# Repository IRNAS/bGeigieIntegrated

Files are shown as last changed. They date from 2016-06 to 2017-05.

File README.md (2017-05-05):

# bGeigieIntegrated
#### Integrated version of Safecast bGeigie device

We created an integrated version of the bGeigie device, a mobile survey Geiger counter. Our PCB is based on orginal design by [Safecast](https://github.com/Safecast/bGeigieNanoKit). We removed various breakout boards and instead placed most of the components directly on the PCB. Our design uses [RedBear Duo](https://github.com/redbear/Duo) as a central processing unit, instead of Arduino Fio. The entire circuit can be powered through USB connector on RedBear, or from a 3.7V LiPo battery. The circuit also includes a battery charger. For control of the Geiger gas tube the iRover is being used, just like in the original design. A LED and a piezo buzzer signalyze the incoming pulses. FGPMMOPA6H GPS receiver from Adafruit retrieves the current position of the device and an accelerometer/magnetometer (LSM303C form ST Microelectronics) measures acceleration and orientation of it. Data are being logged on a micro SD card. A socket for the XBee module is also included, which enables connection to an external logger. A monochrome, 128x32 pixels wide OLED graphical display from [Adafruit](https://www.adafruit.com/product/938) displays a simple user interface. Accelerometer/magnetometer uses an I2C interface. SD card and OLED display communicate via SPI. XBee and GPS module are using an UART interface.

-

#### Changes in schematic:

* Power supply:
 * automatic switch between battery or USB powered mode
 * software power-down
* GPS module:
 * connection to battery
 * uFL connector for external antenna
* OLED display:
 * changed to I2C interface
 * added socket for alternative [display](https://www.amazon.com/Diymall%C2%AE-Yellow-Serial-Arduino-Display/dp/B00O2LLT30)
* magnetic buzzer with integrated oscillator
* high brigthess LEDs for COUNT and LOG indication
* added rotary encoder

---

#### License

All our projects are as usefully open-source as possible.

Hardware including documentation is licensed under [CERN OHL v.1.2. license](http://www.ohwr.org/licenses/cern-ohl/v1.2)

Firmware and software originating from the project is licensed under [GNU GENERAL PUBLIC LICENSE v3](http://www.gnu.org/licenses/gpl-3.0.en.html).

Open data generated by our projects is licensed under [CC0](https://creativecommons.org/publicdomain/zero/1.0/legalcode).

All our websites and additional documentation are licensed under [Creative Commons Attribution-ShareAlike 4 .0 Unported License] (https://creativecommons.org/licenses/by-sa/4.0/legalcode).

What this means is that you can use hardware, firmware, software and documentation without paying a royalty and knowing that you'll be able to use your version forever. You are also free to make changes but if you share these changes then you have to do so on the same conditions that you enjoy.

Koruza, GoodEnoughCNC and IRNAS are all names and marks of Institut IRNAS Rače. 
You may use these names and terms only to attribute the appropriate entity as required by the Open Licences referred to above. You may not use them in any other way and in particular you may not use them to imply endorsement or authorization of any hardware that you design, make or sell.

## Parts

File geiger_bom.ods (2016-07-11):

Designator | Package | Quantity | Description | Price (one piece) | Price (total) | Supplier link
U13 | SSD1306 blue, yellow 0.96" Inch OLED display module for Arduino, I2C | 1 | small I2C OLED | 9,790 € | 9,79 € | https://www.amazon.com/Diymall%C2%AE-Yellow-Serial-Arduino-Display/dp/B00O2LLT30 (https://www.amazon.com/Diymall®-Yellow-Serial-Arduino-Display/dp/B00O2LLT30)
U4 | Adafruit 1.3 inch 128x64 monochrome OLED display | 1 | OLED | 22,190 € | 22,19 € | https://www.adafruit.com/product/938
C1,C3,C4,C6,C7,C8,C9,C10,C12,C15,C17 | C0603 | 11 | 100nF | 0,007 € | 0,08 € | http://si.farnell.com/walsin/0603b104k250ct/capacitor-mlcc-x7r-0-1uf-25v-0603/dp/2496833RL
C16,C18 | C0603 | 2 | 10nF | 0,005 € | 0,01 € | http://si.farnell.com/walsin/0603b103k500ct/capacitor-mlcc-x7r-0-01uf-50v/dp/2496828
C20 | C0603 | 1 | 1uF | 0,009 € | 0,01 € | http://si.farnell.com/murata/grm188r61c105ka12d/cap-mlcc-x5r-1uf-16v-0603/dp/2362099
C2,C5,C11,C19 | tantalum capacitor size B | 4 | 10uF, 10V | 0,333 € | 1,33 € | http://si.farnell.com/kemet/t491b106k010at/cap-tant-10uf-10v-case-b/dp/2283564
C13,C14 | tantalum capacitor size B | 2 | 1uF, 10V | 0,444 € | 0,89 € | http://si.farnell.com/kemet/t491b105k025at/cap-tant-1uf-25v-case-b/dp/2321211
D1 | LED0603 | 1 | GREEN | 0,342 € | 0,34 € | http://si.farnell.com/vishay/tlmp1100-gs08/led-0603-green/dp/1328306
D2 | KPD-3224SURCK | 1 | RED | 0,132 € | 0,13 € | http://si.farnell.com/kingbright/kpd-3224surck/led-smd-dome-lens-red/dp/2146458
D3 | MCL053SGC | 1 | GREEN | 0,239 € | 0,24 € | http://si.farnell.com/multicomp/mcl053sgc/led-5mm-16-super-green/...
D4 | SOD-323 | 1 | 1N4148 | 0,057 € | 0,06 € | http://si.farnell.com/vishay-semiconductor/1n4148ws-e3-08/switching-diode-100v-150ma-sod/dp/2164233
D5 | LED0603 | 1 | RED | 0,285 € | 0,29 € | http://si.farnell.com/vishay/tlms1000-gs08/led-0603-red-4mcd-628nm/dp/1328308
D6 | SOD-323 | 1 | BAT20J | 0,291 € | 0,29 € | http://si.farnell.com/stmicroelectronics/bat20jfilm/diode-schottky-2a-23v/dp/1467541
P4 | B3B-PH-SM4-TB | 1 | IRover connector (receptacle) | 0,382 € | 0,38 € | http://si.farnell.com/jst-japan-solderless-terminals/b3b-ph-sm4-tb-lf-sn/connector-header-smt-2mm-3way/...
P7 | B2B-PH-SM4-TB | 1 | battery connector (receptacle) | 0,318 € | 0,32 € | http://si.farnell.com/jst-japan-solderless-terminals/b2b-ph-sm4-tb-lf-sn/connector-header-smt-2mm-2way/...
Q1,Q4 | SOT-23-3 | 2 | ZXMP6A13F | 0,447 € | 0,89 € | http://si.farnell.com/diodes-inc/zxmp6a13fta/mosfet-p-ch-60v-0-9a-sot23-3/dp/1843770
Q2,Q3,Q6,Q7 | SOT-23-3 | 4 | RSR010N10FHATL | 0,720 € | 2,88 € | http://si.farnell.com/rohm/rsr010n10fhatl/mosfet-n-ch-100v-1a-tsmt-3/dp/2527973
Q5 | SOT-23-3 | 1 | BC847C | 0,380 € | 0,38 € | http://si.farnell.com/nxp/bc847c-215/transistor-npn-45v-sot-23/dp/1081235
R1,R10,R13,R17,R18 | R0603 | 5 | 1K | 0,004 € | 0,02 € | http://si.farnell.com/multicomp/mcwr06x1001ftl/res-thick-film-1k-1-0-1w-0603/dp/2447272
R2,R9 | R0603 | 2 | 9.1K | 0,001 € | 0,00 € | http://si.farnell.com/multicomp/mc0063w060319k1/res-thick-film-9k1-1-0-063w-0603/dp/9331611
R3 | R0603 | 1 | 100K | 0,001 € | 0,00 € | http://si.farnell.com/multicomp/mc0063w06031100k/res-thick-film-100k-1-0-063w-0603/dp/9330402RL
R4,R5,R6,R7,R19,R27,R28,R29,R30,R31,R32,R33 | R0603 | 12 | 10K | 0,001 € | 0,01 € | http://si.farnell.com/multicomp/mc0063w0603110k/res-thick-film-10k-1-0-063w-0603/dp/9330399RL
R8,R12,R15,R16,R21 | R0603 | 5 | 470K | 0,001 € | 0,01 € | http://si.farnell.com/multicomp/mc0063w06031470k/res-thick-film-470k-1-0-063w-0603/dp/9331263RL
R11 | R0603 | 1 | 51R | 0,002 € | 0,00 € | http://si.farnell.com/multicomp/mc0063w0603151r/res-thick-film-51r-1-0-063w-0603/dp/9331336
R14 | R0603 | 1 | 51K | 0,001 € | 0,00 € | http://si.farnell.com/multicomp/mc0063w0603151k/res-thick-film-51k-1-0-063w-0603/dp/9331310RL
R20 | R0603 | 1 | 68R | 0,002 € | 0,00 € | http://si.farnell.com/multicomp/mc0063w0603168r/res-thick-film-68r-1-0-063w-0603/dp/9331484
R24,R25,R26 | R0603 | 2 | 0R | 0,003 € | 0,01 € | http://si.farnell.com/multicomp/mcwr06x000-ptl/res-thick-film-0-ohm-jumper-0/dp/2447743RL
SW2 | A6S-3102-H | 1 | switch DIP-3 | 1,214 € | 1,21 € | http://si.farnell.com/omron-electronic-components/a6s3102h/switch-dip-3-way-sealed/...
U1 | Adafruit Ultimate GPS Module - MTK3339 chipset | 1 | FGPMMOPA6H | 27,120 € | 27,12 € | https://www.adafruit.com/product/790
U2 | SOT-23-5 | 1 | MAX1555 | 2,070 € | 2,07 € | http://si.farnell.com/maxim-integrated-products/max1555ezk-t/battery-charger-li-ion-280ma-sot/dp/2516725
U3 | Xbee socket | 1 | XBee | 19,940 € | 19,94 € | http://si.farnell.com/digi-international/xb24-awi-001/rf-module-txrx-xbee-wire-ant/dp/1337912
U5 | MOLEX 47309-2651 | 1 | micro SD card slot | 1,540 € | 1,54 € | http://si.farnell.com/molex/47309-2651/connector-micro-sd-header-smt/dp/1568092
U6 | SOT-223-3 | 1 | MCP1826S, 3.3V | 0,661 € | 0,66 € | http://si.farnell.com/microchip/mcp1826s-3302e-db/ic-ldo-3-3v-1a-sot-223-3/...
U7 | RedBear Duo socket | 1 | RedBear Duo | 22,570 € | 22,57 € | https://store.redbear.cc/product/wifi-ble/redbear-duo.html
U9 | SOT-23-6 | 1 | LM3880 | 0,644 € | 0,64 € | http://si.farnell.com/texas-instruments/lm38801ae-nopb/power-sequencer-25ua-5-5v-sot/dp/2492198
U10 | SOT-23-5 | 1 | MIC5205, 3.3V | 0,382 € | 0,38 € | http://si.farnell.com/microchip/mic5205-3-3ym5-tr/ic-ldo-150ma-3-3v-ln-sot23-5/dp/2510222
U11 | LD-BZEG-1205 | 1 | magnetic buzzer with internal oscillator | 0,537 € | 0,54 € | http://www.tme.eu/gb/details/ld-bzeg-1205/electromagnetic-sounders-with-generator/loudity/
P1 | U.FL-R-SMT | 1 | uFL connector | 0,578 € | 0,58 € | http://si.farnell.com/hirose-hrs/u-fl-r-smt-1-10/rf-coaxial-u-fl-straight-jack/dp/1688077
SW1 | OS102011MA1QN1 | 1 | slide switch | 0,309 € | 0,31 € | http://si.farnell.com/c-k-components/os102011ma1qn1/switch-spdt-0-1a-12v-pcb-r-a/...
L1 | R0603 | 1 | ferrite bead | 0,036 € | 0,04 € | http://si.farnell.com/murata/blm18bb100sn1d/ferrite-bead-10-ohm-700ma-0603/dp/1515687
P2 | SeedStudio DIP Grove 4P-2.0 | 1 | I2C connector | 1,360 € | 1,36 € | https://www.seeedstudio.com/item_detail.html?p_id=789
U12 | Bourns EC12R-4217F-S0024 | 1 | rotary encoder with switch | 1,150 € | 1,15 € | http://eu.mouser.com/ProductDetail/Bourns/PEC12R-4217F-S0024/...
U14 | TSOT-23-6 | 1 | LTC4412 | 4,650 € | 4,65 € | http://si.farnell.com/linear-technology/ltc4412hs6-trmpbf/...
U15 | SOT-363-6 (SC-70) | 1 | Si1967DH | 0,300 € | 0,30 € | http://si.farnell.com/vishay/si1967dh-t1-ge3/mosfet-dual-p-channel-20v-1-3a/dp/2459406
U8 | LGA-12 | 1 | LSM303C | 2,620 € | 2,62 € | http://eu.mouser.com/ProductDetail/STMicroelectronics/LSM303CTR/?qs=sGAEpiMZZMvnsdhmqAkjhpKxrN6XHrqG
XX | JST PHR-3 | 1 | IRover connector (plug) | 0,090 € | 0,09 € | http://www.digikey.com/product-search/en?keywords=jst%20phr-3
 |  |  |  | Total: | 128,32 €

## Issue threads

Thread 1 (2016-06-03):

ReadBear resets when switching from battery to USB power supply

MatejGomboc, 2016-06-03:
ReadBear resets when switching from battery to USB power supply. No glicth on 3v3 line has been detected.

thinrope, 2016-11-15:
This seems to be by (mis-)design?
https://github.com/redbear/Duo/blob/4939729db3e4c0e1d01a7ab4786c5cb1f7083013/docs/duo_introduction.md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

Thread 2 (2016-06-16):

LSM303C wrong footprint

MatejGomboc, 2016-06-16:
The footprint of LSM303C is wrong.

MatejGomboc, 2016-06-20:
Corrected in version: 93a449f8909264a0c31f38d7b277a518afbb46ec.

Closed 2016-06-20.

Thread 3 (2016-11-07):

Accelerometer/Magnetometer Library Incompatible

MatejGomboc, 2016-11-07:
Library for accelerometer/magnetometer is incompatible with LSM303C.

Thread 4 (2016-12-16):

Some suggestions.

robouden, 2016-12-16:
- power switch bigger and stronger
- more options for displays (maybe jumpers)
- test for SPI display running on Redbear Duo wold be usefull

SloMusti, 2017-01-07:
Please list displays you believe would be useful and support can be added.

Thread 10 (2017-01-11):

Battery connector

SloMusti, 2017-01-11:
User a better battery connector, such that it does not break that simply.

SloMusti, 2017-01-12:
Also move connector about 5mm towards the inside of the board, so it is not on the edge.

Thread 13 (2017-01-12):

Buzzer dual drive

SloMusti, 2017-01-12:
Make the buzzer such that it receives the signal input at the same time from geiger tube and processor.

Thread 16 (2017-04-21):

Evaluate current consumption of small and large OLED display.

fakufaku, 2017-04-21:
@robouden used a large 2.4" display
vs
The standard 1.3" display used before

If the large display is used, it should be moved to the center of the pcb to appear in the large clear area of the Pelican case.

robouden, 2017-07-15:
Large OLED based unit runs 12 hours on a full charged 3000mA LiPo

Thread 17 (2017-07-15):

Charging Issues

robouden, 2017-07-15:
When the unit is charging it switch on and off. If let on long time the LiPo get overcharged, gets very hot  and start smelling.

robouden, 2017-07-15:
Would be nice if we could detect the unit is charging and disable the soft startup.

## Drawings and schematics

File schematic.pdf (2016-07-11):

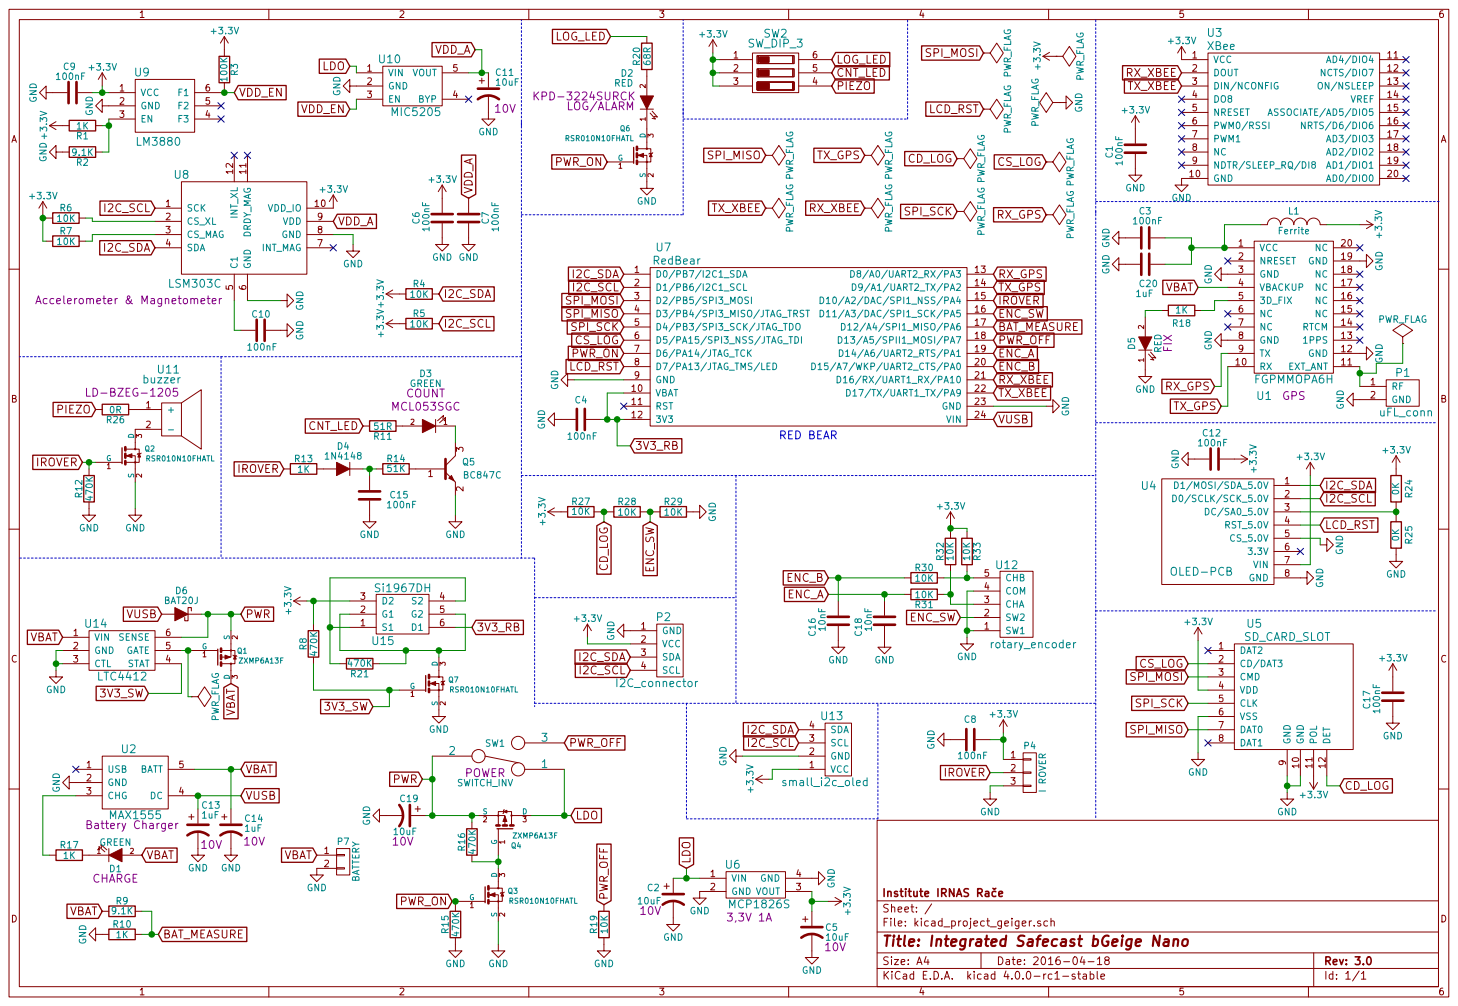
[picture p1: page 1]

9 GND 10 POL 11 DET 12 U5 SD_CARD_SLOT VBAT

Institute IRNAS Rae
File: kicad_project_geiger.sch Sheet: /
Id: 1/1 Title: Integrated Safecast bGeige Nano

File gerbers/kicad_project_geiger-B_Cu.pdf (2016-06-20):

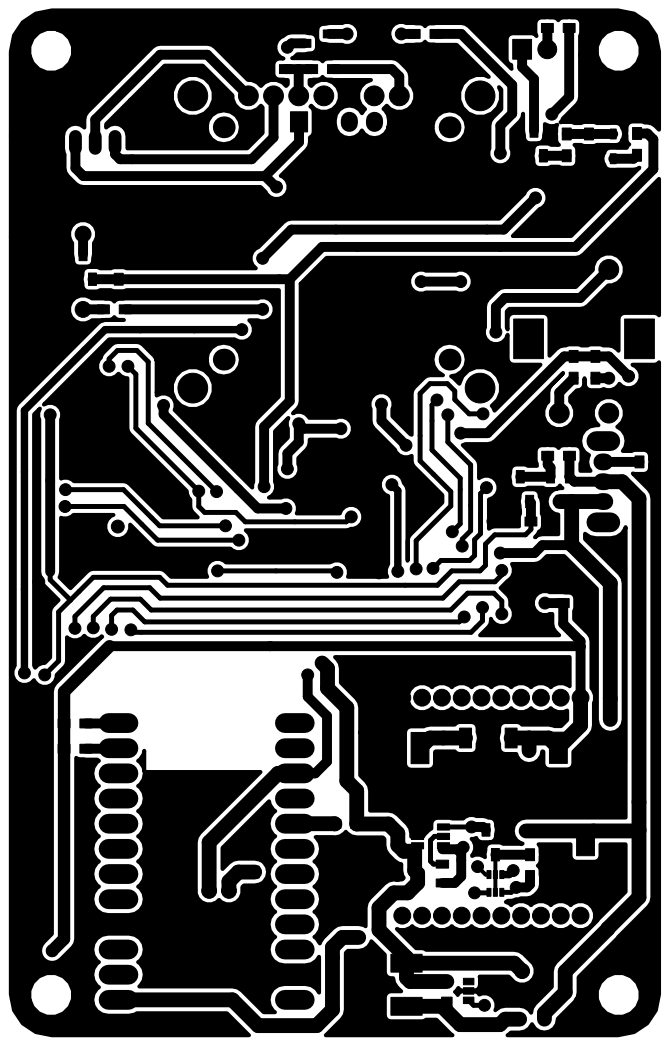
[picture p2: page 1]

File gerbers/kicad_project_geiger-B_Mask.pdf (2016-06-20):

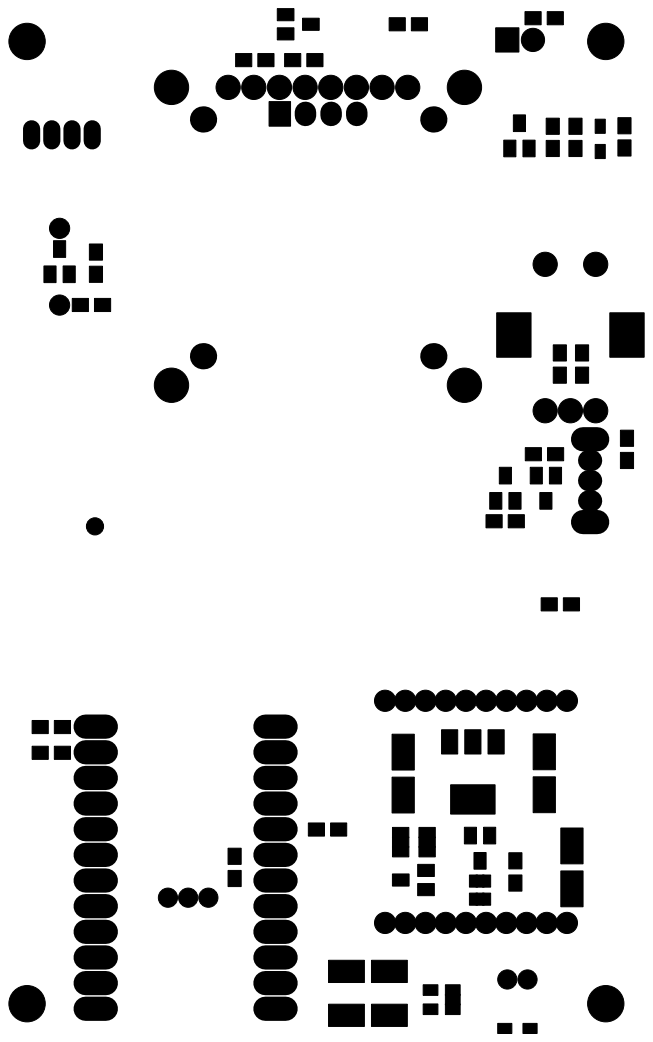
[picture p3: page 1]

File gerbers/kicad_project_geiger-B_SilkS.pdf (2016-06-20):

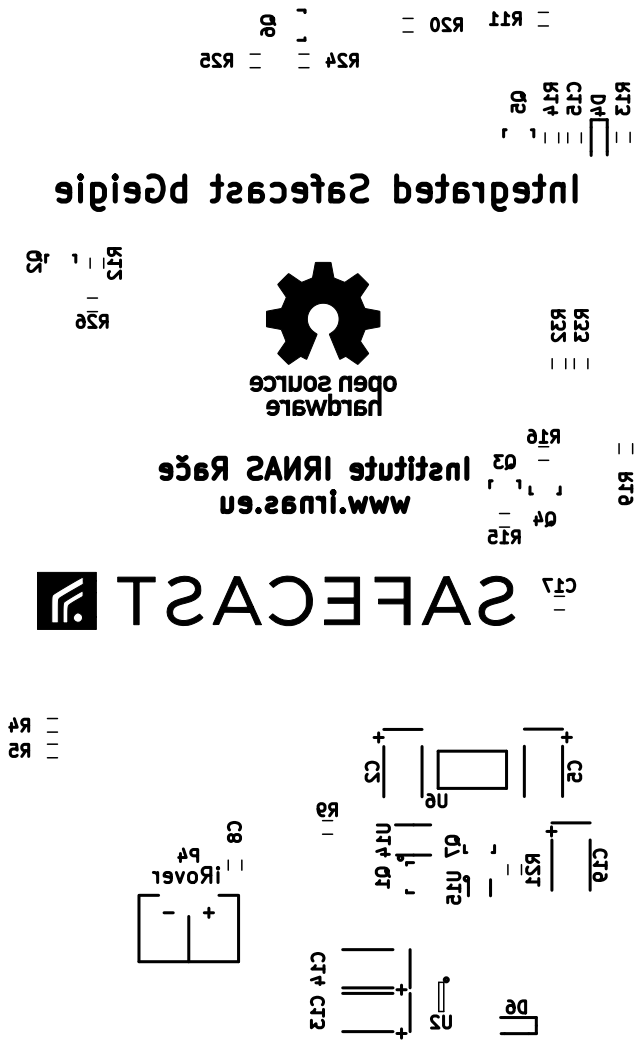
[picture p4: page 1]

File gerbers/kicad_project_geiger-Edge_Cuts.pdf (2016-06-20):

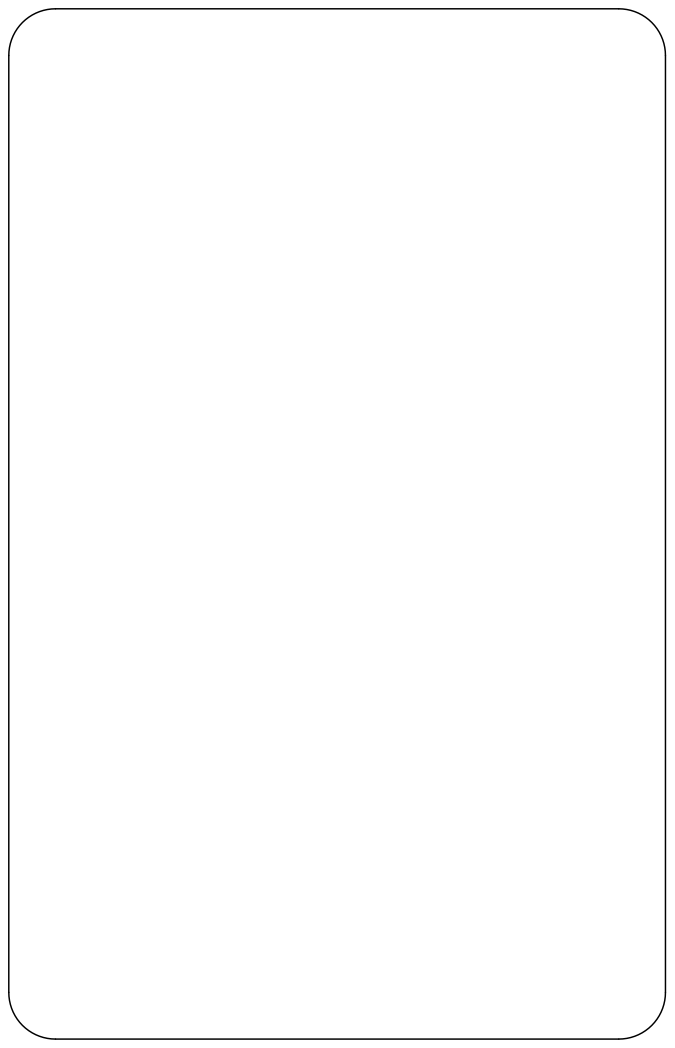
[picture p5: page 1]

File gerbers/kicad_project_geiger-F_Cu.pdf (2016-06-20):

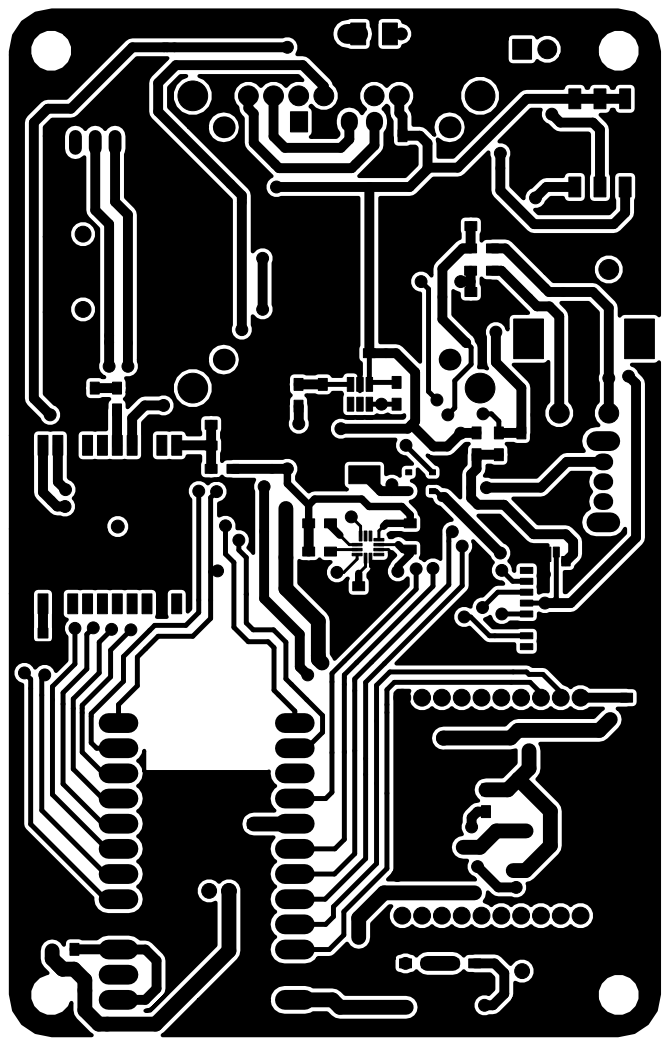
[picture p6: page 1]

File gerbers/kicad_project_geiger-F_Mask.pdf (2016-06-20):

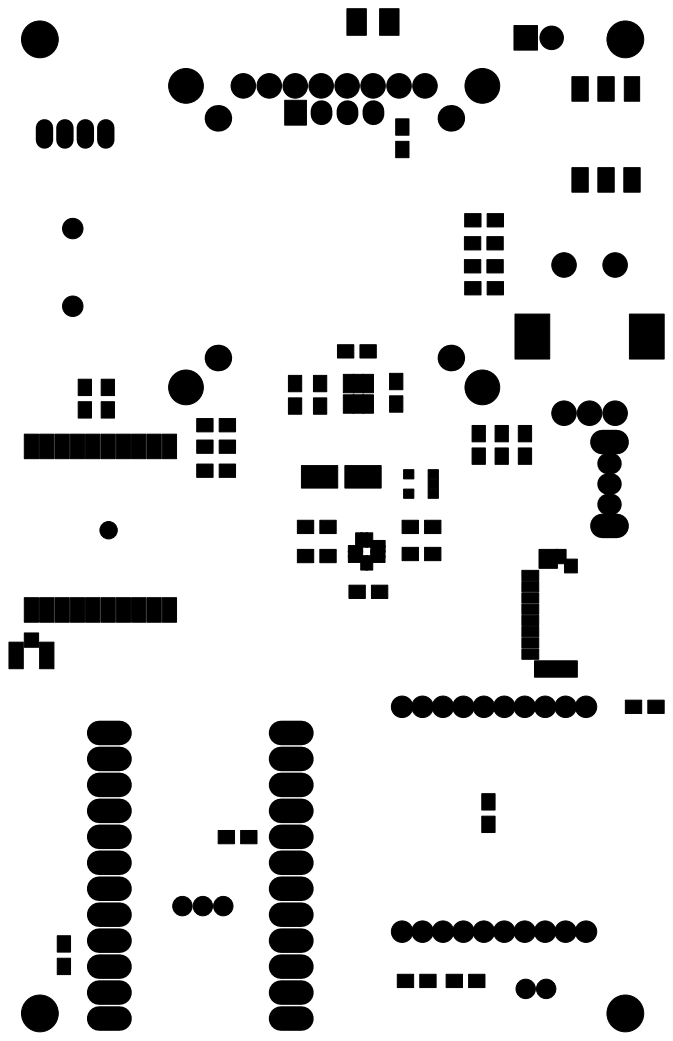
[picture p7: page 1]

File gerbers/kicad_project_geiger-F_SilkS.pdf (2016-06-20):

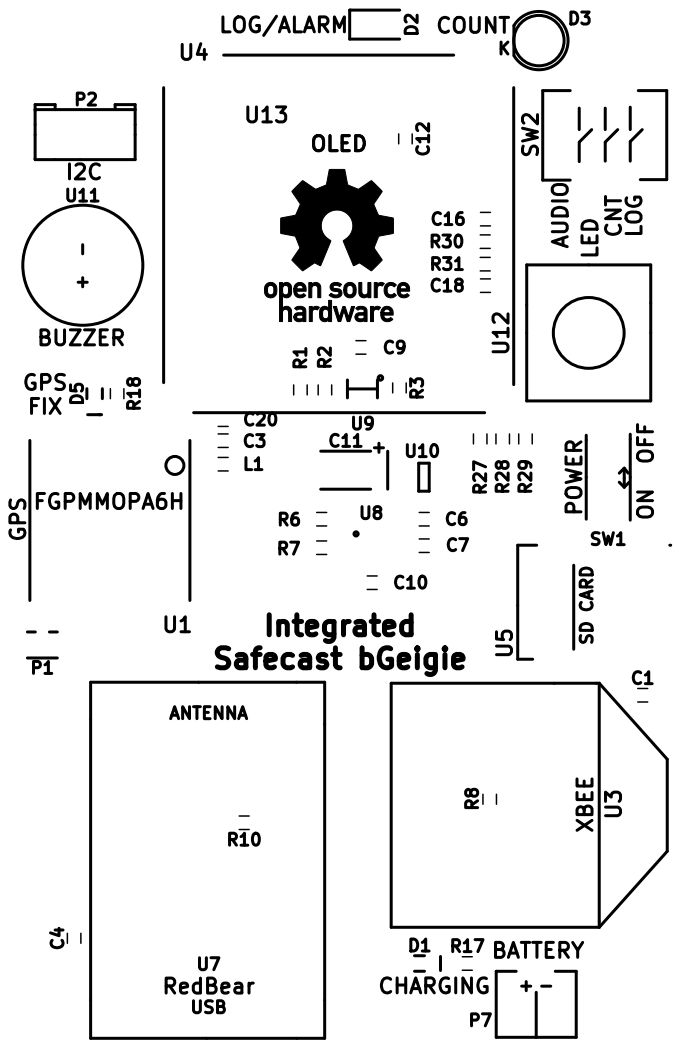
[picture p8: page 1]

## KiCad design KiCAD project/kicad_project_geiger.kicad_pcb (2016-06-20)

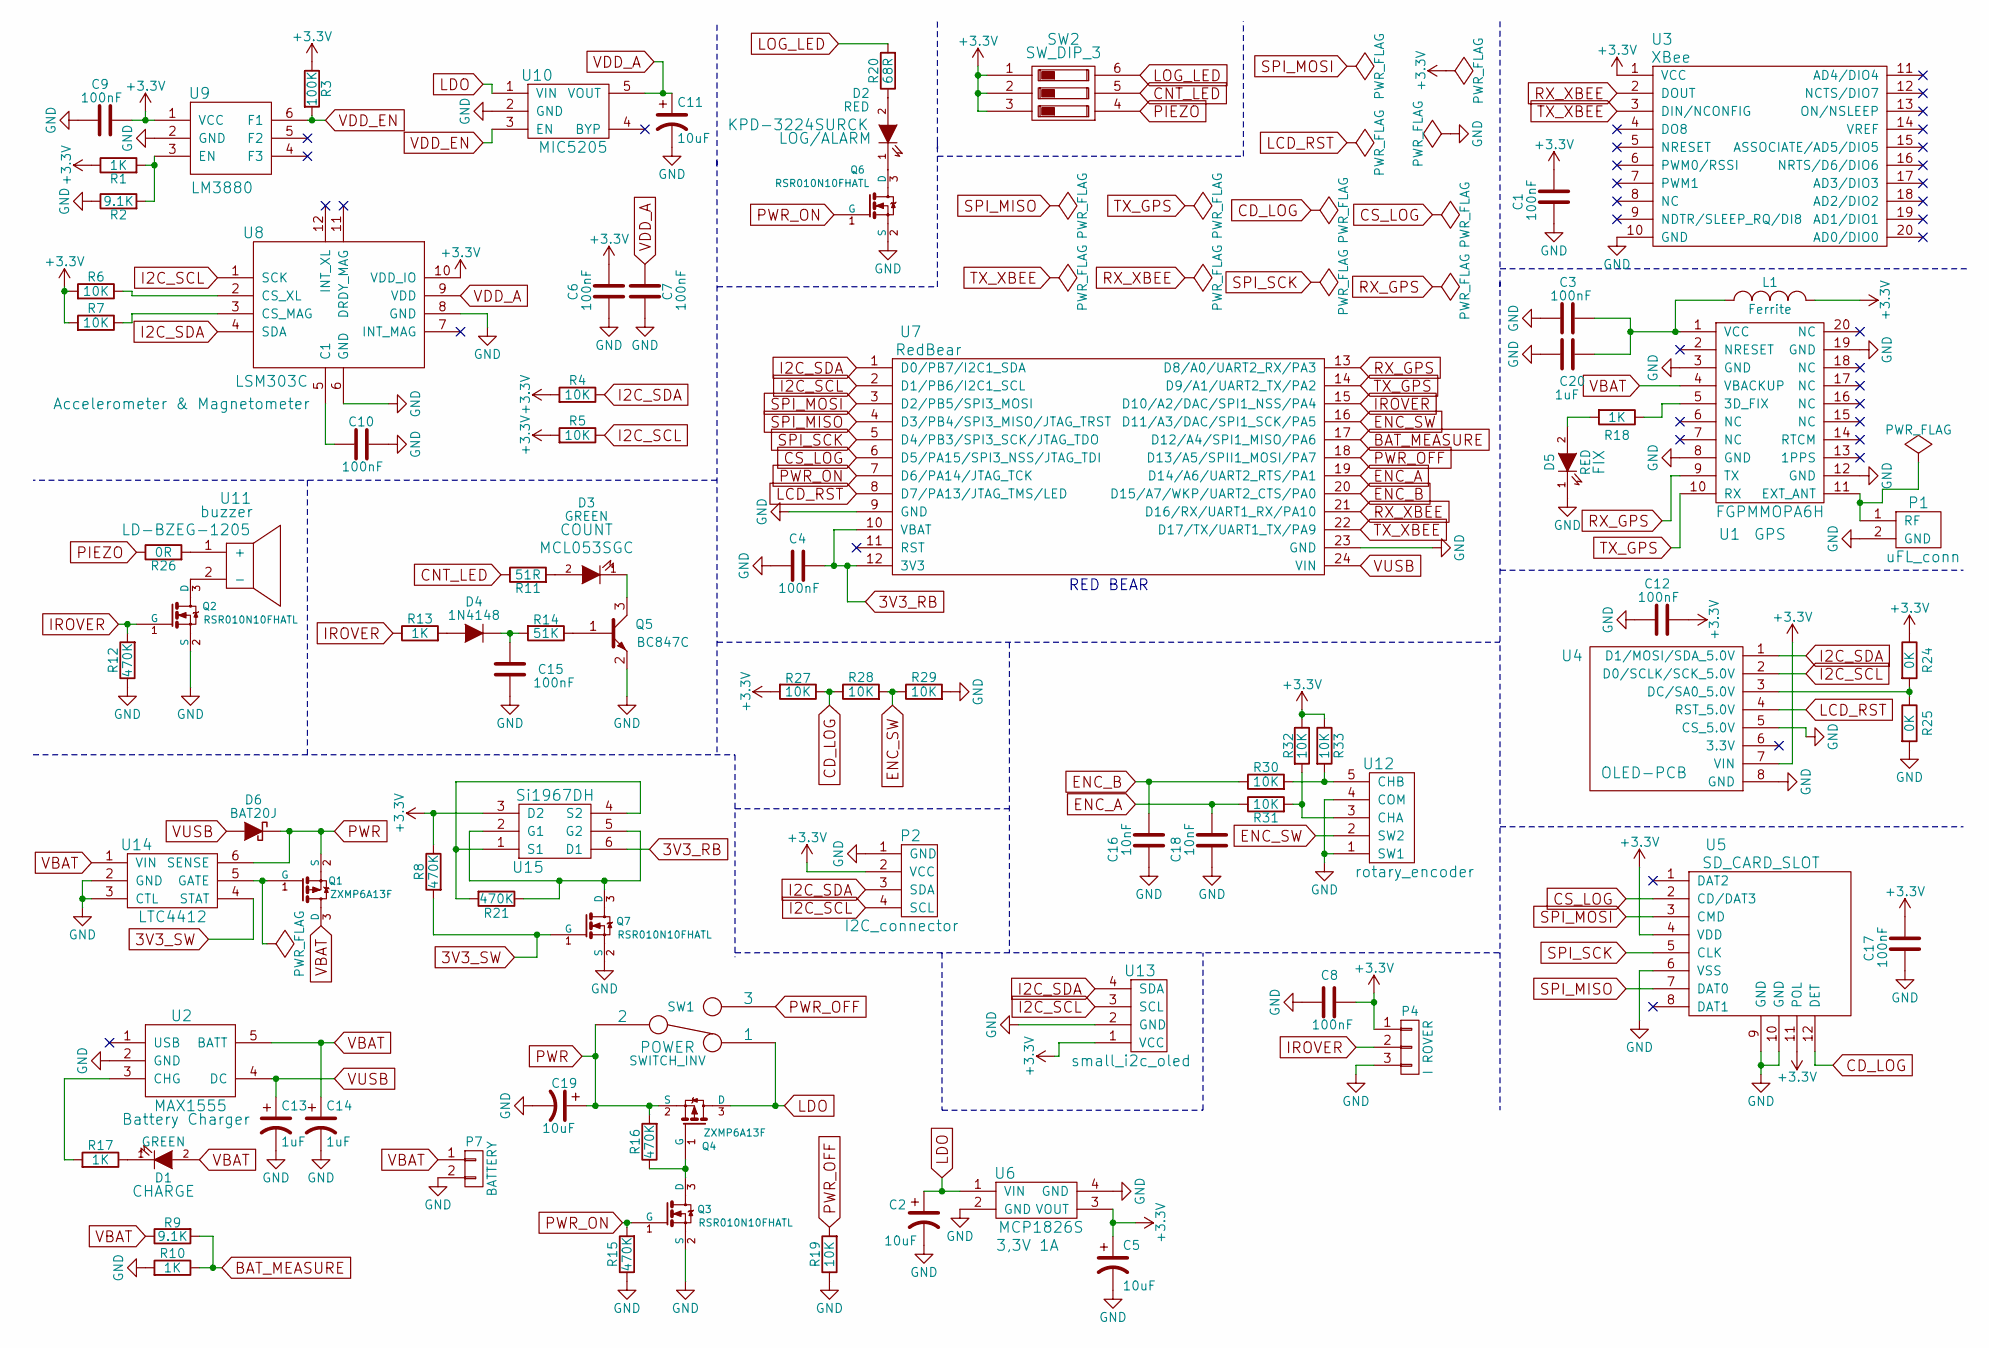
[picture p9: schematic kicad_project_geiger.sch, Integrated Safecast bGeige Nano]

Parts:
C1, C3, C4, C6, C7, C8, C9, C10, C12, C15, C17: 100nF; R_0603_HandSoldering
C2, C5, C11, C19: 10uF; TantalC_SizeB_EIA-3528_HandSoldering
C13, C14: 1uF; TantalC_SizeB_EIA-3528_HandSoldering
C16, C18: 10nF; R_0603_HandSoldering
C20: 1uF; R_0603_HandSoldering
D1: GREEN; LED_0603_HandSoldering
D2: RED; KPD-3224SURCK
D3: GREEN; MCL053SGC
D4: 1N4148; SOD-323
D5: RED; LED_0603_HandSoldering
D6: BAT20J; SOD-323
L1: Ferrite; R_0603_HandSoldering
P1: uFL_conn; U.FL-R-SMT
P2: I2C_connector; DIP_Grove_4P-2_0
P4: I ROVER; B3B-PH-SM4-TB_IROVER_CONNECTOR
P7: BATTERY; B2B-PH-SM4-TB_Battery_Connector
Q1, Q4: ZXMP6A13F; SOT-23
Q2, Q3, Q6, Q7: RSR010N10FHATL; SOT-23
Q5: BC847C; SOT-23
R1, R10, R13, R17, R18: 1K; R_0603_HandSoldering
R2, R9: 9.1K; R_0603_HandSoldering
R3: 100K; R_0603_HandSoldering
R4, R5, R6, R7, R19, R27, R28, R29, R30, R31, R32, R33: 10K; R_0603_HandSoldering
R8, R12, R15, R16, R21: 470K; R_0603_HandSoldering
R11: 51R; R_0603_HandSoldering
R14: 51K; R_0603_HandSoldering
R20: 68R; R_0603_HandSoldering
R24, R25: 0K; R_0603_HandSoldering
R26: 0R; R_0603_HandSoldering
SW1: SWITCH_INV; OS102011MA1QN1_slide_switch
SW2: SW_DIP_3; OMRON_ELECTRONIC_COMPONENTS_A6S-3102-H_DIP_Switch
U1: FGPMMOPA6H; FGPMMOPA6H_GPS
U2: MAX1555; SOT-23-5
U3: XBee; xbee
U4: OLED-PCB; Adafruit-1_3inch-128x64-Mono-OLED-PCB-master
U5: SD_CARD_SLOT; MOLEX_47309-2651_CONNECTOR_MICRO_SD
U6: MCP1826S; MCP1826S_SOT223
U7: RedBear
U8: LSM303C
U9: LM3880
U10: MIC5205
U11: buzzer; LD-BZEG-1205
U12: rotary_encoder; rotary_enc_bourns_EC12R-4215F-S0024
U13: small_i2c_oled; Small_I2C_OLED
U14: LTC4412
U15: Si1967DH

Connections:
3V3_RB: C4.2, U7.10 (VBAT), U7.12 (3V3), U15.6 (D1)
3V3_SW: Q7.1 (G), R8.2, U14.4 (STAT)
+3V3: C1.2, C5.1, C6.2, C8.1, C9.2, C12.2, C17.2, L1.2, P2.2 (VCC), P4.1, R1.1, R3.1, R4.2, R5.2, R6.2, R7.2, R8.1, R24.1, R27.2, R32.1, R33.1, SW2.1, SW2.2, SW2.3, U3.1 (VCC), U4.7 (VIN), U5.4 (VDD), U5.11 (POL), U6.3 (VOUT), U8.10 (VDD_IO), U9.1 (VCC), U13.1 (VCC), U15.3 (D2)
BAT_MEASURE: R9.2, R10.1, U7.17 (D12/A4/SPI1_MISO/PA6)
CD_LOG: R27.1, R28.1, U5.12 (DET)
CNT_LED: R11.1, SW2.5
CS_LOG: U5.2 (CD/DAT3), U7.6 (D5/PA15/SPI3_NSS/JTAG_TDI)
ENC_A: C18.2, R31.1, U7.19 (D14/A6/UART2_RTS/PA1)
ENC_B: C16.2, R30.1, U7.20 (D15/A7/WKP/UART2_CTS/PA0)
ENC_SW: R28.2, R29.1, U7.16 (D11/A3/DAC/SPI1_SCK/PA5), U12.2 (SW2)
GND: C1.1, C2.2, C3.2, C4.1, C5.2, C6.1, C7.1, C8.2, C9.1, C10.2, C11.2, C12.1, C13.2, C14.2, C15.2, C16.1, C17.1, C18.1, C19.2, C20.2, D5.1 (K), P1.2 (GND), P2.1 (GND), P4.3, P7.2, Q2.2 (S), Q3.2 (S), Q5.2 (E), Q6.2 (S), Q7.2 (S), R2.1, R10.2, R12.1, R15.1, R19.1, R25.2, R29.2, U1.3 (GND), U1.8 (GND), U1.12 (GND), U1.19 (GND), U2.2 (GND), U3.10 (GND), U4.5 (CS_5.0V), U4.8 (GND), U5.6 (VSS), U5.9 (GND), U5.10 (GND), U6.2 (GND), U6.4 (GND), U7.9 (GND), U7.23 (GND), U8.6 (GND), U8.8 (GND), U9.2 (GND), U10.2 (GND), U12.1 (SW1), U12.4 (COM), U13.2 (GND), U14.2 (GND), U14.3 (CTL)
I2C_SCL: P2.4 (SCL), R5.1, U4.2 (D0/SCLK/SCK_5.0V), U7.2 (D1/PB6/I2C1_SCL), U8.1 (SCK), U13.3 (SCL)
I2C_SDA: P2.3 (SDA), R4.1, U4.1 (D1/MOSI/SDA_5.0V), U7.1 (D0/PB7/I2C1_SDA), U8.4 (SDA), U13.4 (SDA)
IROVER: P4.2, Q2.1 (G), R12.2, R13.1, U7.15 (D10/A2/DAC/SPI1_NSS/PA4)
LCD_RST: U4.4 (RST_5.0V), U7.8 (D7/PA13/JTAG_TMS/LED)
LDO: C2.1, Q4.3 (D), SW1.1, U6.1 (VIN), U10.1 (VIN)
LOG_LED: R20.2, SW2.6
unnamed: C10.1, U8.5 (C1)
unnamed: C15.1, D4.1 (K), R14.2
unnamed: C3.1, C20.1, L1.1, U1.1 (VCC)
unnamed: D1.1 (K), R17.1
unnamed: D2.1 (K), Q6.3 (D)
unnamed: D2.2 (A), R20.1
unnamed: D3.1 (K), Q5.3 (C)
unnamed: D3.2 (A), R11.2
unnamed: D4.2 (A), R13.2
unnamed: D5.2 (A), R18.2
unnamed: P1.1 (RF), U1.11 (EXT_ANT)
unnamed: Q1.1 (G), U14.5 (GATE)
unnamed: Q2.3 (D), U11.2 (-)
unnamed: Q3.3 (D), Q4.1 (G), R16.1
unnamed: Q5.1 (B), R14.1
unnamed: Q7.3 (D), R21.1, U15.2 (G1), U15.5 (G2)
unnamed: R1.2, R2.2, U9.3 (EN)
unnamed: R6.1, U8.2 (CS_XL)
unnamed: R7.1, U8.3 (CS_MAG)
unnamed: R17.2, U2.3 (CHG)
unnamed: R18.1, U1.5 (3D_FIX)
unnamed: R21.2, U15.1 (S1), U15.4 (S2)
unnamed: R24.2, R25.1, U4.3 (DC/SA0_5.0V)
unnamed: R26.2, U11.1 (+)
unnamed: R30.2, R33.2, U12.5 (CHB)
unnamed: R31.2, R32.2, U12.3 (CHA)
PIEZO: R26.1, SW2.4
PWR: C19.1, D6.1 (K), Q1.2 (S), Q4.2 (S), R16.2, SW1.2, U14.6 (SENSE)
PWR_OFF: R19.2, SW1.3, U7.18 (D13/A5/SPII1_MOSI/PA7)
PWR_ON: Q3.1 (G), Q6.1 (G), R15.2, U7.7 (D6/PA14/JTAG_TCK)
RX_GPS: U1.9 (TX), U7.13 (D8/A0/UART2_RX/PA3)
RX_XBEE: U3.2 (DOUT), U7.21 (D16/RX/UART1_RX/PA10)
SPI_MISO: U5.7 (DAT0), U7.4 (D3/PB4/SPI3_MISO/JTAG_TRST)
SPI_MOSI: U5.3 (CMD), U7.3 (D2/PB5/SPI3_MOSI)
SPI_SCK: U5.5 (CLK~), U7.5 (D4/PB3/SPI3_SCK/JTAG_TDO)
TX_GPS: U1.10 (RX), U7.14 (D9/A1/UART2_TX/PA2)
TX_XBEE: U3.3 (DIN/NCONFIG), U7.22 (D17/TX/UART1_TX/PA9)
VBAT: C14.1, D1.2 (A), P7.1, Q1.3 (D), R9.1, U1.4 (VBACKUP), U2.5 (BATT), U14.1 (VIN)
VDD_A: C7.2, C11.1, U8.9 (VDD), U10.5 (VOUT)
VDD_EN: R3.2, U9.6 (F1), U10.3 (EN)
VUSB: C13.1, D6.2 (A), U2.4 (DC), U7.24 (VIN)

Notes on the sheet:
RED BEAR

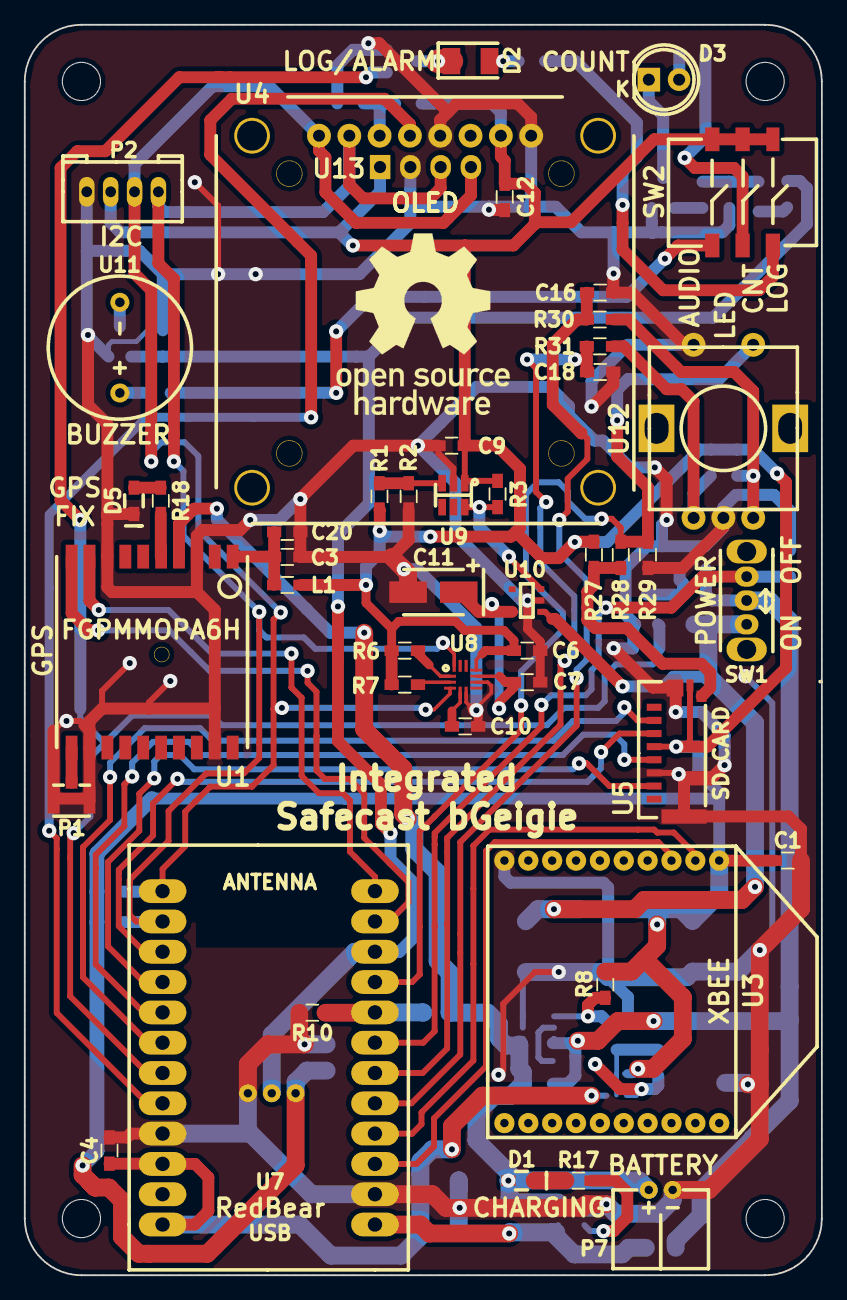
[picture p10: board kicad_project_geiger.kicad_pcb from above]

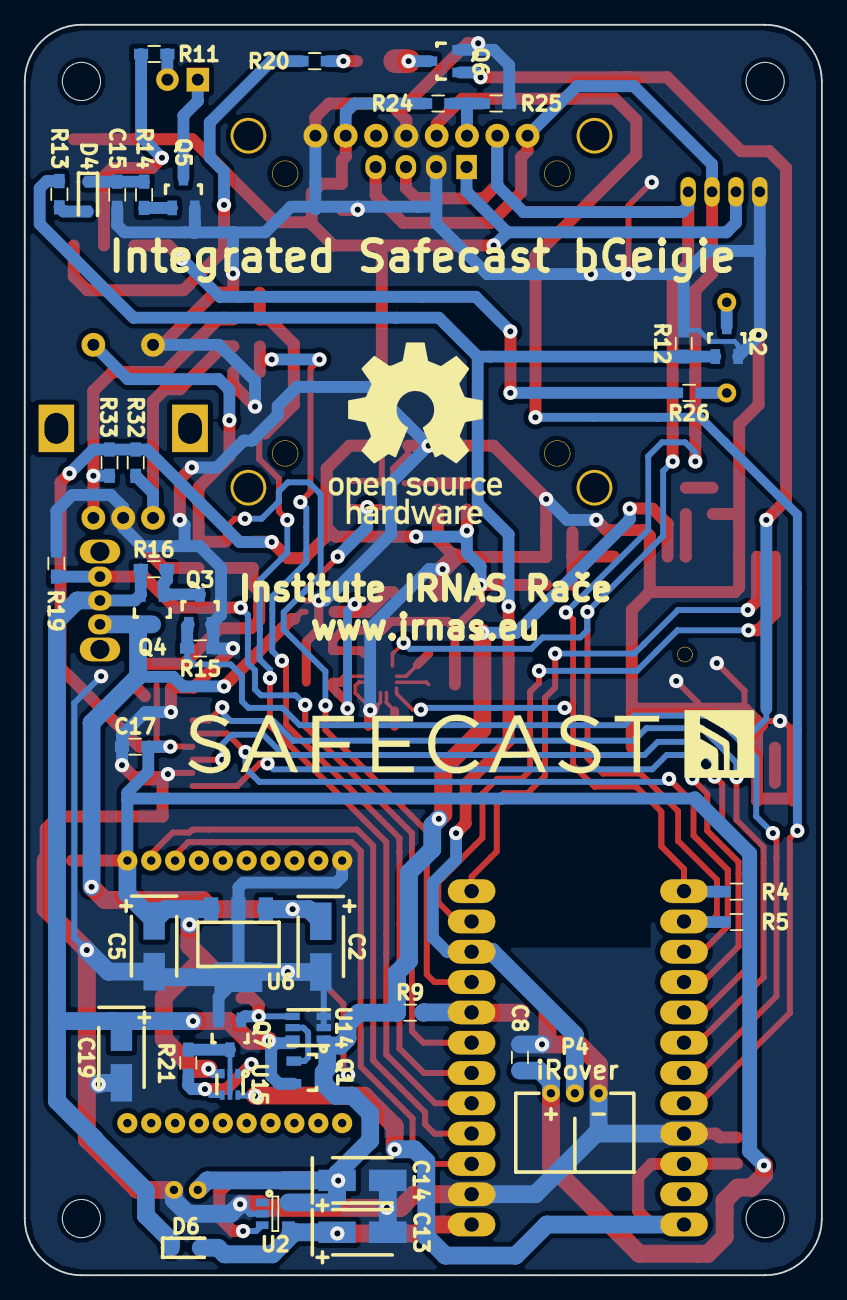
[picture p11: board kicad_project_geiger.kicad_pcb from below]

Board: 2 copper layers, 66.8 x 104.8 mm, 86 parts (39 on the bottom side), 58 nets.

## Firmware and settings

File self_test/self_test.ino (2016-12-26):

#if defined(ARDUINO)
SYSTEM_MODE(MANUAL);//do not connect to cloud
#else
SYSTEM_MODE(AUTOMATIC);//connect to cloud
#endif

#include "Adafruit_GPS.h"
#include "application.h"
#include "Adafruit_GFX.h"
#include "Adafruit_SSD1306.h"
#include "Adafruit_Sensor.h"
#include "Adafruit_LSM303.h"

#undef ARDUINO
#define PLATFORM_ID 3
#include "SdFat.h"

// Secondary SPI with DMA
// SCK => D4, MISO => D3, MOSI => D2, SS => D5
SdFat sd(1);
const uint8_t chipSelect = D5;

File myFile;
Adafruit_LSM303 lsm;

int IROVER = A2;
int BAT_MEAS = A4;
int ENC_SWITCH = A3;
int ENCODER_A = A6;
int ENCODER_B = A7;
int POWER_ON_SWITCH = D6;
int POWER_OFF_DETECT = A5;

#define OLED_RESET 7 // LCD_RST = D7
Adafruit_SSD1306 display(OLED_RESET);

static const unsigned char PROGMEM logo16_glcd_bmp[] =
{
  0x00, 0xC0,
  0x01, 0xC0,
  0x01, 0xC0,
  0x03, 0xE0,
  0xF3, 0xE0,
  0xFE, 0xF8,
  0x7E, 0xFF,
  0x33, 0x9F,
  0x1F, 0xFC,
  0x0D, 0x70,
  0x1B, 0xA0,
  0x3F, 0xE0,
  0x3F, 0xF0,
  0x7C, 0xF0,
  0x70, 0x70,
  0x00, 0x30
};

#if (SSD1306_LCDHEIGHT != 64)
#error("Height incorrect, please fix Adafruit_SSD1306.h!");
#endif

void test_irover();
void i2c_scan();
void test_batt_volt_measure();
void test_encoder_switch_card_detect();
void test_encoder();
void test_gps();
void test_oled();
void test_sdcard();
void test_acc();
void test_sw_pwdwn();
void detect_power_switch_off();

void setup()
{
  Serial.begin(115200);

  //pinMode(IROVER, INPUT);
  pinMode(IROVER, OUTPUT);
  pinMode(ENCODER_A, INPUT);
  pinMode(ENCODER_B, INPUT);
  pinMode(POWER_ON_SWITCH, OUTPUT);
  pinMode(POWER_OFF_DETECT, INPUT);

  //OLED:

  // by default, we'll generate the high voltage from the 3.3v line internally! (neat!)
  display.begin(SSD1306_SWITCHCAPVCC, 0x3D);  // initialize with the I2C addr 0x3D (for the 128x64)
  // init done

  // Show image buffer on the display hardware.
  // Since the buffer is intialized with an Adafruit splashscreen
  // internally, this will display the splashscreen.
  display.display();

  delay(1000);

  // Clear the buffer.
  display.clearDisplay();

  //END OLED
}

void loop()
{
  test_irover();
  test_sw_pwdwn();
  i2c_scan();
  test_batt_volt_measure();
  test_encoder_switch_card_detect();
  test_encoder();
  //test_gps();
  //test_oled();
  test_sdcard();
  detect_power_switch_off();
  //test_acc();
}

void test_irover()
{
  for (int i = 0; i < 3; i++)
  {
    Serial.println("\ntest iRover:");

    digitalWrite(IROVER, HIGH);

    delay(1000);

    digitalWrite(IROVER, LOW);

    delay(1000);
  }
}

void i2c_scan()
{
  Serial.println("\nI2C Scanner:");

  Wire.begin();
  delay(1000);

  byte error, address;
  int nDevices;

  Serial.println("Scanning...");

  nDevices = 0;

  for (address = 0; address < 127; address++ )
  {
    // The i2c_scanner uses the return value of
    // the Write.endTransmisstion to see if
    // a device did acknowledge to the address.
    Wire.beginTransmission(address);
    error = Wire.endTransmission();

    //Serial.println(address);

    if (error == 0)
    {
      Serial.print("I2C device found at address 0x");
      if (address < 16)
        Serial.print("0");
      Serial.print(address, HEX);
      Serial.println("  !");

      nDevices++;
    }
    else if (error == 4)
    {
      Serial.print("Unknow error at address 0x");
      if (address < 16)
        Serial.print("0");
      Serial.println(address, HEX);
    }
  }
  if (nDevices == 0)
    Serial.println("No I2C devices found\n");
  else
    Serial.println("done\n");

  delay(1000);
}

void test_batt_volt_measure()
{
  Serial.println("\nmeasure battery voltage:");
  delay(1000);

  for (int i = 0; i < 50; i++)
  {
    //// bat voltage
    Serial.println(((double)analogRead(BAT_MEAS) * 3.3 * 10.12) / 4096.0); // debug value
  }
}

void test_encoder_switch_card_detect()
{
  Serial.println("\ntest encoder switch:");
  Serial.println("press encoder button!");
  delay(1000);

  if (((double)analogRead(ENC_SWITCH) * 3.3) / 4096.0 > 1.2) Serial.println("SD card inserted!");
  else Serial.println("SD card not detected!");

  for (int i = 0; i < 20; i++)
  {
    //// ENC_SW
    Serial.println(((double)analogRead(ENC_SWITCH) * 3.3) / 4096.0); // debug value
    delay(1000);
  }
}

void test_encoder()
{
  int encoder0Pos = 0;
  bool encoder0PinALast = LOW;
  bool n = LOW;

  Serial.println("\ntest encoder:");
  Serial.println("rotate encoder!");
  Serial.println("Press encoder button to continue!");
  delay(1000);

  while (true)
  {
    n = digitalRead(ENCODER_A);
    if ((encoder0PinALast == LOW) && (n == HIGH))
    {
      if (digitalRead(ENCODER_B) == LOW)
      {
        encoder0Pos--;
      }
      else
      {
        encoder0Pos++;
      }
      Serial.print (encoder0Pos);
      Serial.print ("/");
    }
    encoder0PinALast = n;

    if (((double)analogRead(ENC_SWITCH) * 3.3) / 4096.0 < 0.5) break;
  }
}

void test_gps()
{
  Serial.println("\ntest GPS:");
  Serial.println("Adafruit GPS library basic test!");
  Serial.println("Press encoder button to continue!");

  Serial2.begin(9600);
  Adafruit_GPS GPS(&Serial2);

  // 9600 NMEA is the default baud rate for MTK - some use 4800
  GPS.begin(9600);

  // You can adjust which sentences to have the module emit, below

  // uncomment this line to turn on RMC (recommended minimum) and GGA (fix data) including altitude
  //GPS.sendCommand(PMTK_SET_NMEA_OUTPUT_RMCGGA);
  // uncomment this line to turn on only the "minimum recommended" data for high update rates!
  //GPS.sendCommand(PMTK_SET_NMEA_OUTPUT_RMCONLY);
  // uncomment this line to turn on all the available data - for 9600 baud you'll want 1 Hz rate
  GPS.sendCommand(PMTK_SET_NMEA_OUTPUT_ALLDATA);

  // Set the update rate
  // Note you must send both commands below to change both the output rate (how often the position
  // is written to the serial line), and the position fix rate.
  // 1 Hz update rate
  GPS.sendCommand(PMTK_SET_NMEA_UPDATE_1HZ);
  GPS.sendCommand(PMTK_API_SET_FIX_CTL_1HZ);
  // 5 Hz update rate- for 9600 baud you'll have to set the output to RMC or RMCGGA only (see above)
  //GPS.sendCommand(PMTK_SET_NMEA_UPDATE_5HZ);
  //GPS.sendCommand(PMTK_API_SET_FIX_CTL_5HZ);
  // 10 Hz update rate - for 9600 baud you'll have to set the output to RMC only (see above)
  // Note the position can only be updated at most 5 times a second so it will lag behind serial output.
  //GPS.sendCommand(PMTK_SET_NMEA_UPDATE_10HZ);
  //GPS.sendCommand(PMTK_API_SET_FIX_CTL_5HZ);

  // Request updates on antenna status, comment out to keep quiet
  GPS.sendCommand(PGCMD_ANTENNA);

  delay(1000);

  while (true)
  {
    //Serial.println("reading");
    //Serial.print(GPS.read());
    if (Serial2.available())
    {
      char c = Serial2.read();
      if (c) Serial.print(c);
    }

    if (((double)analogRead(ENC_SWITCH) * 3.3) / 4096.0 < 0.5) break;
  }
}

void test_oled()
{
  Serial.println("\ntest OLED:");

  // Clear the buffer.
  display.clearDisplay();

  // draw the first ~12 characters in the font

  display.setTextSize(1);
  display.setTextColor(WHITE);
  display.setCursor(0, 0);

  for (uint8_t i = 0; i < 168; i++)
  {
    if (i == '\n') continue;
    display.write(i);
    if ((i > 0) && (i % 21 == 0))
      display.println();
  }
  display.display();
  delay(1);

  display.display();
  delay(2000);
  display.clearDisplay();
}

void test_sdcard()
{
  Serial.println("\ntest SD card:");

  // Initialize SdFat or print a detailed error message and halt
  // Use half speed like the native library.
  // Change to SPI_FULL_SPEED for more performance.
  if (!sd.begin(chipSelect, SPI_HALF_SPEED)) {
    sd.initErrorHalt();
  }

  // open the file for write at end like the "Native SD library"
  if (!myFile.open("test.txt", O_RDWR | O_CREAT | O_AT_END)) {
    sd.errorHalt("opening test.txt for write failed");
  }
  // if the file opened okay, write to it:
  Serial.print("Writing to test.txt...");
  myFile.println("testing 1, 2, 3.");
  myFile.printf("fileSize: %d\n", myFile.fileSize());

  // close the file:
  myFile.close();
  Serial.println("done.");

  // re-open the file for reading:
  if (!myFile.open("test.txt", O_READ)) {
    sd.errorHalt("opening test.txt for read failed");
  }
  Serial.println("test.txt content:");

  // read from the file until there's nothing else in it:
  int data;
  while ((data = myFile.read()) >= 0) {
    Serial.write(data);
  }
  // close the file:
  myFile.close();
}

void test_acc()
{
  Serial.println("\ntest accelerometer:");

  // Try to initialize and warn if we couldn't detect the chip
  if (!lsm.begin())
  {
    Serial.println("Oops ... unable to initialize the LSM303. Check your wiring!");
  }

  Serial.println("test");
  lsm.read();
  Serial.print("Accel X: "); Serial.print((int)lsm.accelData.x); Serial.print(" ");
  Serial.print("Y: "); Serial.print((int)lsm.accelData.y);       Serial.print(" ");
  Serial.print("Z: "); Serial.println((int)lsm.accelData.z);     Serial.print(" ");
  Serial.print("Mag X: "); Serial.print((int)lsm.magData.x);     Serial.print(" ");
  Serial.print("Y: "); Serial.print((int)lsm.magData.y);         Serial.print(" ");
  Serial.print("Z: "); Serial.println((int)lsm.magData.z);       Serial.print(" ");
  delay(100);
}

void test_sw_pwdwn()
{
  // bridge the power off switch
  digitalWrite(POWER_ON_SWITCH, HIGH);
  Serial.println("\ntest software power-down:");
  Serial.println("Power off switch bridged!");
}

void detect_power_switch_off()
{
  if (digitalRead(POWER_OFF_DETECT)) Serial.println("\nPower switch turned off!");
}

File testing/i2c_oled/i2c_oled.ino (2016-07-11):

/*********************************************************************
  This is an example for our Monochrome OLEDs based on SSD1306 drivers

  Pick one up today in the adafruit shop!
  ------> http://www.adafruit.com/category/63_98

  This example is for a 128x64 size display using I2C to communicate
  3 pins are required to interface (2 I2C and one reset)

  Adafruit invests time and resources providing this open source code,
  please support Adafruit and open-source hardware by purchasing
  products from Adafruit!

  Written by Limor Fried/Ladyada  for Adafruit Industries.
  BSD license, check license.txt for more information
  All text above, and the splash screen must be included in any redistribution
*********************************************************************/

//#include <SPI.h>
#include "application.h"
//#include <Wire.h>
#include "Adafruit_GFX.h"
#include "Adafruit_SSD1306.h"

#define OLED_RESET 7
Adafruit_SSD1306 display(OLED_RESET);

#define NUMFLAKES 10
#define XPOS 0
#define YPOS 1
#define DELTAY 2


#define LOGO16_GLCD_HEIGHT 16
#define LOGO16_GLCD_WIDTH  16
static const unsigned char PROGMEM logo16_glcd_bmp[] =
{ 0x00, 0xC0,
  0x01, 0xC0,
  0x01, 0xC0,
  0x03, 0xE0,
  0xF3, 0xE0,
  0xFE, 0xF8,
  0x7E, 0xFF,
  0x33, 0x9F,
  0x1F, 0xFC,
  0x0D, 0x70,
  0x1B, 0xA0,
  0x3F, 0xE0,
  0x3F, 0xF0,
  0x7C, 0xF0,
  0x70, 0x70,
  0x00, 0x30
};

#if (SSD1306_LCDHEIGHT != 64)
#error("Height incorrect, please fix Adafruit_SSD1306.h!");
#endif

void testdrawbitmap(const uint8_t *bitmap, uint8_t w, uint8_t h) {
  uint8_t icons[NUMFLAKES][3];

  // initialize
  for (uint8_t f = 0; f < NUMFLAKES; f++) {
    icons[f][XPOS] = random(display.width());
    icons[f][YPOS] = 0;
    icons[f][DELTAY] = random(5) + 1;

    Serial.print("x: ");
    Serial.print(icons[f][XPOS], DEC);
    Serial.print(" y: ");
    Serial.print(icons[f][YPOS], DEC);
    Serial.print(" dy: ");
    Serial.println(icons[f][DELTAY], DEC);
  }

  while (1) {
    // draw each icon
    for (uint8_t f = 0; f < NUMFLAKES; f++) {
      display.drawBitmap(icons[f][XPOS], icons[f][YPOS], bitmap, w, h, WHITE);
    }
    display.display();
    delay(200);

    // then erase it + move it
    for (uint8_t f = 0; f < NUMFLAKES; f++) {
      display.drawBitmap(icons[f][XPOS], icons[f][YPOS], bitmap, w, h, BLACK);
      // move it
      icons[f][YPOS] += icons[f][DELTAY];
      // if its gone, reinit
      if (icons[f][YPOS] > display.height()) {
        icons[f][XPOS] = random(display.width());
        icons[f][YPOS] = 0;
        icons[f][DELTAY] = random(5) + 1;
      }
    }
  }
}


void testdrawchar(void) {
  display.setTextSize(1);
  display.setTextColor(WHITE);
  display.setCursor(0, 0);

  for (uint8_t i = 0; i < 168; i++) {
    if (i == '\n') continue;
    display.write(i);
    if ((i > 0) && (i % 21 == 0))
      display.println();
  }
  display.display();
  delay(1);
}

void testdrawcircle(void) {
  for (int16_t i = 0; i < display.height(); i += 2) {
    display.drawCircle(display.width() / 2, display.height() / 2, i, WHITE);
    display.display();
    delay(1);
  }
}

void testfillrect(void) {
  uint8_t color = 1;
  for (int16_t i = 0; i < display.height() / 2; i += 3) {
    // alternate colors
    display.fillRect(i, i, display.width() - i * 2, display.height() - i * 2, color % 2);
    display.display();
    delay(1);
    color++;
  }
}

void testdrawtriangle(void) {
  for (int16_t i = 0; i < min(display.width(), display.height()) / 2; i += 5) {
    display.drawTriangle(display.width() / 2, display.height() / 2 - i,
                         display.width() / 2 - i, display.height() / 2 + i,
                         display.width() / 2 + i, display.height() / 2 + i, WHITE);
    display.display();
    delay(1);
  }
}

void testfilltriangle(void) {
  uint8_t color = WHITE;
  for (int16_t i = min(display.width(), display.height()) / 2; i > 0; i -= 5) {
    display.fillTriangle(display.width() / 2, display.height() / 2 - i,
                         display.width() / 2 - i, display.height() / 2 + i,
                         display.width() / 2 + i, display.height() / 2 + i, WHITE);
    if (color == WHITE) color = BLACK;
    else color = WHITE;
    display.display();
    delay(1);
  }
}

void testdrawroundrect(void) {
  for (int16_t i = 0; i < display.height() / 2 - 2; i += 2) {
    display.drawRoundRect(i, i, display.width() - 2 * i, display.height() - 2 * i, display.height() / 4, WHITE);
    display.display();
    delay(1);
  }
}

void testfillroundrect(void) {
  uint8_t color = WHITE;
  for (int16_t i = 0; i < display.height() / 2 - 2; i += 2) {
    display.fillRoundRect(i, i, display.width() - 2 * i, display.height() - 2 * i, display.height() / 4, color);
    if (color == WHITE) color = BLACK;
    else color = WHITE;
    display.display();
    delay(1);
  }
}

void testdrawrect(void) {
  for (int16_t i = 0; i < display.height() / 2; i += 2) {
    display.drawRect(i, i, display.width() - 2 * i, display.height() - 2 * i, WHITE);
    display.display();
    delay(1);
  }
}

void testdrawline() {
  for (int16_t i = 0; i < display.width(); i += 4) {
    display.drawLine(0, 0, i, display.height() - 1, WHITE);
    display.display();
    delay(1);
  }
  for (int16_t i = 0; i < display.height(); i += 4) {
    display.drawLine(0, 0, display.width() - 1, i, WHITE);
    display.display();
    delay(1);
  }
  delay(250);

  display.clearDisplay();
  for (int16_t i = 0; i < display.width(); i += 4) {
    display.drawLine(0, display.height() - 1, i, 0, WHITE);
    display.display();
    delay(1);
  }
  for (int16_t i = display.height() - 1; i >= 0; i -= 4) {
    display.drawLine(0, display.height() - 1, display.width() - 1, i, WHITE);
    display.display();
    delay(1);
  }
  delay(250);

  display.clearDisplay();
  for (int16_t i = display.width() - 1; i >= 0; i -= 4) {
    display.drawLine(display.width() - 1, display.height() - 1, i, 0, WHITE);
    display.display();
    delay(1);
  }
  for (int16_t i = display.height() - 1; i >= 0; i -= 4) {
    display.drawLine(display.width() - 1, display.height() - 1, 0, i, WHITE);
    display.display();
    delay(1);
  }
  delay(250);

  display.clearDisplay();
  for (int16_t i = 0; i < display.height(); i += 4) {
    display.drawLine(display.width() - 1, 0, 0, i, WHITE);
    display.display();
    delay(1);
  }
  for (int16_t i = 0; i < display.width(); i += 4) {
    display.drawLine(display.width() - 1, 0, i, display.height() - 1, WHITE);
    display.display();
    delay(1);
  }
  delay(250);
}
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

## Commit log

2016-04-07 New schematic proposal
2016-07-11 Update
    Updated BOM and schematic.
    [geiger_bom.ods, kicad_project_geiger.sch]
